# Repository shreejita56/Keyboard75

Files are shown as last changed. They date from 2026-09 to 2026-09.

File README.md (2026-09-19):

# Keyboard75


SO I made a custom 75 % layout Mechanical keyboard which has a rotor encoder at the top for brightness controlee as well . It is based on rp2040 chip  . SO I had to design the MCU circuit by myself as well . The PCB was designed on kicad and CAD was done on Fusion . firmware was written in VS-Code. It has a very compact design. The Keyboard also includes per switch LED and diodes to prevent ghosting. It connects to the PC via USB-C input .

## Features
 - Based on Rp2040 chip
 - had compact 75% keyboard layout
 - Per Switch LED and diode for ghosting prevention
 - USB-C Type for Connection
 - Uplifted CAD Design for comfortable typing

##  BOM

| Comment | Footprint | Quantity | Total Price ($) | Link |
|---|---|---:|---:|---|
| 33pF | 0603 | 4 | 0.0236 | https://jlcpcb.com/partdetail/2015-CL10C330JB8NNNC/C1663 |
| 0.1uF | 0603 | 10 | 0.124 | https://jlcpcb.com/partdetail/YAGEO-CC0603KRX7R9BB104/C14663 |
| 100nF | 0603 | 10 | 0.124 | https://jlcpcb.com/partdetail/YAGEO-CC0603KRX7R9BB104/C14663 |
| 10uF | 0603 | 4 | 0.1276 | https://jlcpcb.com/partdetail/20411-CL10A106KP8NNNC/C19702 |
| 1uF | 0603 | 4 | 0.0684 | https://jlcpcb.com/partdetail/16531-CL10A105KB8NNNC/C15849 |
| USB_C_Receptacle_USB2.0_16P | USB_C_Receptacle_G-Switch_GT-USB-7010ASV | 2 | 0.0988 | https://jlcpcb.com/partdetail/DEALON-USB_TYPE_C006/C2927026 |
| 5.1K | 0603 | 4 | 0.0076 | https://jlcpcb.com/partdetail/23913-0603WAF5101T5E/C23186 |
| 1K | 0603 | 4 | 0.0132 | https://jlcpcb.com/partdetail/21904-0603WAF1001T5E/C21190 |
| 27ohm | 0603 | 20 | 0.022 | https://jlcpcb.com/partdetail/23790019-RCA0327RJLF/C22356575 |
| 10K | 0603 | 4 | 0.0108 | https://jlcpcb.com/partdetail/26547-0603WAF1002T5E/C25804 |
| RP2040 | QFN-56-1EP_7x7mm_P0.4mm_EP3.2x3.2mm | 2 | 1.979 | https://jlcpcb.com/partdetail/RaspberryPi-RP2040/C2040 |
| 12MHz | Crystal_SMD_3225-4Pin_3.2x2.5mm | 5 | 2.14 | https://jlcpcb.com/partdetail/KDSDaishinku-DSX321G12MHz/C93234 |
| PCB + 3D Prints Cost | — | 1 | 30.80 | https://jlcpcb.com |
| PCBA Cost | — | 1 | 27.88 | https://jlcpcb.com |
| PCB Shipping | — | 1 | 14.03 | https://jlcpcb.com |
| Hot-swap | — | 90 | 6.75 | https://meckeys.com/shop/accessories/keyboard-accessories/key-switches/kailh-hot-swap-socket/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 |
| Mechanical Switch | — | 90 | 21.10 | https://meckeys.com/shop/accessories/keyboard-accessories/key-switches/akko-v3-pro-cream-black-switch/ |
| KEY-CAPS | — | 1 | 11.50 | https://meckeys.com/shop/accessories/keyboard-accessories/keycaps/side-engraved-keycap-set/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 |
| 0.1uF Capacitor | 0603 | 90 | 3.60 | https://sharvielectronics.com/product/0-1uf-16v-capacitor-0603-smd-package/ |
| 1N4007 Diodes | SOD-123FL | 90 | 2.60 | https://sharvielectronics.com/product/a7-1n4007-100v-1a-silicon-rectifier-diode-sod-123fl-smd-package/ |
| SK6812MINI-E | — | 90 | 8.10 | https://www.etstore.in/products/e9974?variant=48993209319675 |
| Components Shipping | — | 1 | 3.30 | https://www.etstore.in/ |
| **TOTAL** | — | — | **$132.67** | — |

### Schematic<br><br>


###  PCB Design<br><br>



### 3D Render <br><br>



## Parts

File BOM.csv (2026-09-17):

comment | footprint | description | quantity | total price | link
33pF | 0603 | 33pF 50V C0G ±5% 0603 Multilayer Ceramic Capacitors MLCC - SMD/SMT ROHS | 4 | 0.0236 | https://jlcpcb.com/partdetail/2015-CL10C330JB8NNNC/C1663
0.1uF | 0603 | 100nF 50V X7R ±10% 0603 Multilayer Ceramic Capacitors MLCC - SMD/SMT ROHS | 10 | 0.124 | https://jlcpcb.com/partdetail/YAGEO-CC0603KRX7R9BB104/C14663
100nf | 0603 | 100nF 50V X7R ±10% 0603 Multilayer Ceramic Capacitors MLCC - SMD/SMT ROHS | 10 | 0.124 | https://jlcpcb.com/partdetail/YAGEO-CC0603KRX7R9BB104/C14663
10uF | 0603 | 10V 10uF X5R ±10% 0603 Multilayer Ceramic Capacitors MLCC - SMD/SMT ROHS | 4 | 0.1276 | https://jlcpcb.com/partdetail/20411-CL10A106KP8NNNC/C19702
1uF | 0603 | 1uF 50V X5R ±10% 0603 Multilayer Ceramic Capacitors MLCC - SMD/SMT ROHS | 4 | 0.0684 | https://jlcpcb.com/partdetail/16531-CL10A105KB8NNNC/C15849
USB_C_Receptacle_USB2.0_16P | USB_C_Receptacle_G-Switch_GT-USB-7010ASV | -25℃~+85℃ 1 10000 times 5A 5V 6.8mm 6P Female Surface Mount, Right Angle Type-C SMD USB Connectors ROHS | 2 | 0.0988 | https://jlcpcb.com/partdetail/DEALON-USB_TYPE_C006/C2927026
5.1K | 0603 | -55℃~+155℃ 100mW 5.1kΩ 75V Thick Film Resistor ±1% ±100ppm/℃ 0603 Chip Resistor - Surface Mount ROHS | 4 | 0.0076 | https://jlcpcb.com/partdetail/23913-0603WAF5101T5E/C23186
1K | 0603 | -55℃~+155℃ 100mW 1kΩ 75V Thick Film Resistor ±1% ±100ppm/℃ 0603 Chip Resistor - Surface Mount ROHS | 4 | 0.0132 | https://jlcpcb.com/partdetail/21904-0603WAF1001T5E/C21190
27ohn | 0603 | -55℃~+155℃ 100mW 27Ω 75V Thick Film Resistor ±100ppm/℃ ±5% 0603 Chip Resistor - Surface Mount ROHS | 20 | 0.022 | https://jlcpcb.com/partdetail/23790019-RCA0327RJLF/C22356575
10K | 0603 | -55℃~+155℃ 100mW 10kΩ 75V Thick Film Resistor ±1% ±100ppm/℃ 0603 Chip Resistor - Surface Mount ROHS | 4 | 0.0108 | https://jlcpcb.com/partdetail/26547-0603WAF1002T5E/C25804
RP2040 | QFN-56-1EP_7x7mm_P0.4mm_EP3.2x3.2mm | 12bit 133MHz 30 LQFN-56(7x7) Microcontrollers (MCU/MPU/SOC) ROHS | 2 | 1.979 | https://jlcpcb.com/partdetail/RaspberryPi-RP2040/C2040
12MHz | Crystal_SMD_3225-4Pin_3.2x2.5mm | Crystal Oscillator SMD3225-4P Crystals ROHS | 5 | 2.14 | https://jlcpcb.com/partdetail/KDSDaishinku-DSX321G12MHz/C93234
PCB + 3D Prints Cost |  |  |  | 30.8 | https://jlcpcb.com
PCBA Cost |  |  |  | 27.88 | https://jlcpcb.com
PCB Shipping |  |  |  | 14.03 | https://jlcpcb.com
Hot-swap |  |  | 90 | 6.75 | https://meckeys.com/shop/accessories/keyboard-accessories/key-switches/kailh-hot-swap-socket/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
Mechanical Switch |  |  | 90 | 21.1 | https://meckeys.com/shop/accessories/keyboard-accessories/key-switches/akko-v3-pro-cream-black-switch/
KEY-CAPS |  |  | 1 | 11.5 | https://meckeys.com/shop/accessories/keyboard-accessories/keycaps/side-engraved-keycap-set/
0.1 uf Capacitor |  | Capacitors for Each LEDS | 90 | 3.6 | https://sharvielectronics.com/product/0-1uf-16v-capacitor-0603-smd-package/
1N4007 Diodes |  | for ghosting protection | 90 | 2.6 | https://sharvielectronics.com/product/a7-1n4007-100v-1a-silicon-rectifier-diode-sod-123fl-smd-package/
SK6812MINI-E |  | LEDS | 90 | 8.1 | https://www.etstore.in/products/e9974?variant=48993209319675
Components shipping (from all the three websites except jlcpcb) |  |  |  | 3.3 | www.etstore.in / https://sharvielectronics.com / https://meckeys.com
Total |  |  |  | $132.67

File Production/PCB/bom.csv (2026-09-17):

Designator | Footprint | Quantity | Value | LCSC Part #
_6, _5, _4, _3, _2, |  | 6
C1, C10, C11, C12, C13, C14, C15, C16, C17, C18, C19, C2, C20, C21, C22, C23, C24, C25, C26, C27, C28, C29, C3, C30, C31, C32, C33, C34, C35, C36, C37, C38, C39, C4, C40, C41, C42, C43, C44, C45, C46, C47, C48, C49, C5, C50, C51, C52, C53, C54, C55, C56, C57, C58, C59, C6, C60, C61, C62, C63, C64, C65, C66, C67, C68, C69, C7, C70, C71, C72, C73, C74, C75, C76, C77, C78, C79, C8, C80, C81, C82, C9 | 0805 | 82 | 0.1 uf
C83, C84 | 0603 | 2 | 33pF
C86, C88, C92 | 0603 | 3 | 0.1uF
C87, C91 | 0603 | 2 | 10uF
C94, C98 | 0603 | 2 | 1uF
C95, C97 | 0603 | 2 | 100 nf
D1, D10, D11, D12, D13, D14, D15, D16, D17, D18, D19, D2, D20, D21, D22, D23, D24, D25, D26, D27, D28, D29, D3, D30, D31, D32, D33, D34, D35, D36, D37, D38, D39, D4, D40, D41, D42, D43, D44, D45, D46, D47, D48, D49, D5, D50, D51, D52, D53, D54, D55, D56, D57, D58, D59, D6, D60, D61, D62, D63, D64, D65, D66, D67, D68, D69, D7, D70, D71, D72, D73, D74, D75, D76, D77, D78, D79, D8, D80, D81, D82, D83, D9 | 0805 | 83 | D
J1 | USB_C_Receptacle_G-Switch_GT-USB-7010ASV | 1 | USB_C_Receptacle_USB2.0_16P
LED1 | MX_SK6812MINI-E | 1 | C
LED10, LED11, LED12, LED13, LED14, LED15, LED16, LED17, LED18, LED19, LED2, LED20, LED21, LED22, LED23, LED24, LED25, LED26, LED27, LED28, LED29, LED3, LED30, LED31, LED32, LED33, LED34, LED35, LED36, LED37, LED38, LED39, LED4, LED40, LED41, LED42, LED43, LED44, LED45, LED46, LED47, LED48, LED49, LED5, LED50, LED51, LED52, LED53, LED54, LED55, LED56, LED57, LED58, LED59, LED6, LED60, LED61, LED62, LED63, LED64, LED65, LED66, LED67, LED68, LED69, LED7, LED70, LED71, LED72, LED73, LED74, LED75, LED76, LED77, LED78, LED79, LED8, LED80, LED81, LED82, LED9 | MX_SK6812MINI-E | 81 | ~
R14, R7 | 0603 | 2 | 10K
R3, R4 | 0603 | 2 | 5.1K
R5, R6 | 0603 | 2 | 1K
R8, R9 | 0603 | 2 | 27 ohn
ST28, ST57, ST59 | Stabilizer_Cherry_MX_2.00u | 3 | MountingHole
ST76 | Stabilizer_Cherry_MX_6.25u | 1 | MountingHole
SW1 | SW_Hotswap_Kailh_MX_1.00u | 1 | ESC
SW10 | SW_Hotswap_Kailh_MX_1.00u | 1 | F9
SW11 | SW_Hotswap_Kailh_MX_1.00u | 1 | F10
SW12 | SW_Hotswap_Kailh_MX_1.00u | 1 | F11
SW13 | SW_Hotswap_Kailh_MX_1.00u | 1 | F12
SW14 | SW_Hotswap_Kailh_MX_1.00u | 1 | Delete
SW15 | SW_Hotswap_Kailh_MX_1.00u | 1 | `
SW16 | SW_Hotswap_Kailh_MX_1.00u | 1 | 1
SW17 | SW_Hotswap_Kailh_MX_1.00u | 1 | 2
SW18 | SW_Hotswap_Kailh_MX_1.00u | 1 | 3
SW19 | SW_Hotswap_Kailh_MX_1.00u | 1 | 4
SW2 | SW_Hotswap_Kailh_MX_1.00u | 1 | F1
SW20 | SW_Hotswap_Kailh_MX_1.00u | 1 | 5
SW21 | SW_Hotswap_Kailh_MX_1.00u | 1 | 6
SW22 | SW_Hotswap_Kailh_MX_1.00u | 1 | 7
SW23 | SW_Hotswap_Kailh_MX_1.00u | 1 | 8
SW24 | SW_Hotswap_Kailh_MX_1.00u | 1 | 9
SW25 | SW_Hotswap_Kailh_MX_1.00u | 1 | 0
SW26 | SW_Hotswap_Kailh_MX_1.00u | 1 | -
SW27 | SW_Hotswap_Kailh_MX_1.00u | 1 | +
SW28 | SW_Hotswap_Kailh_MX_1.00u | 1 | Backspace
SW29 | SW_Hotswap_Kailh_MX_1.00u | 1 | Home
SW3 | SW_Hotswap_Kailh_MX_1.00u | 1 | F2
SW30 | SW_Hotswap_Kailh_MX_1.00u | 1 | Tab
SW31 | SW_Hotswap_Kailh_MX_1.00u | 1 | Q
SW32 | SW_Hotswap_Kailh_MX_1.00u | 1 | W
SW33 | SW_Hotswap_Kailh_MX_1.00u | 1 | E
SW34 | SW_Hotswap_Kailh_MX_1.00u | 1 | R
SW35 | SW_Hotswap_Kailh_MX_1.00u | 1 | T
SW36 | SW_Hotswap_Kailh_MX_1.00u | 1 | Y
SW37 | SW_Hotswap_Kailh_MX_1.00u | 1 | U
SW38 | SW_Hotswap_Kailh_MX_1.00u | 1 | I
SW39 | SW_Hotswap_Kailh_MX_1.00u | 1 | O
SW4 | SW_Hotswap_Kailh_MX_1.00u | 1 | F3
SW40 | SW_Hotswap_Kailh_MX_1.00u | 1 | P
SW41 | SW_Hotswap_Kailh_MX_1.00u | 1 | [
SW42 | SW_Hotswap_Kailh_MX_1.00u | 1 | ]
SW43 | SW_Hotswap_Kailh_MX_1.00u | 1 | \
SW44 | SW_Hotswap_Kailh_MX_1.00u | 1 | Pg Up
SW45 | SW_Hotswap_Kailh_MX_1.00u | 1 | Caps Lock
SW46 | SW_Hotswap_Kailh_MX_1.00u | 1 | A
SW47 | SW_Hotswap_Kailh_MX_1.00u | 1 | S
SW48 | SW_Hotswap_Kailh_MX_1.00u | 1 | D
SW49 | SW_Hotswap_Kailh_MX_1.00u | 1 | F
SW5 | SW_Hotswap_Kailh_MX_1.00u | 1 | F4
SW50 | SW_Hotswap_Kailh_MX_1.00u | 1 | G
SW51 | SW_Hotswap_Kailh_MX_1.00u | 1 | H
SW52 | SW_Hotswap_Kailh_MX_1.00u | 1 | J
SW53 | SW_Hotswap_Kailh_MX_1.00u | 1 | K
SW54 | SW_Hotswap_Kailh_MX_1.00u | 1 | L
SW55 | SW_Hotswap_Kailh_MX_1.00u | 1 | ;
SW56 | SW_Hotswap_Kailh_MX_1.00u | 1 | "
SW57 | SW_Hotswap_Kailh_MX_1.00u | 1 | Enter
SW58 | SW_Hotswap_Kailh_MX_1.00u | 1 | Pg Dn
SW59 | SW_Hotswap_Kailh_MX_1.00u | 1 | L Shift
SW6 | SW_Hotswap_Kailh_MX_1.00u | 1 | F5
SW60 | SW_Hotswap_Kailh_MX_1.00u | 1 | Z
SW61 | SW_Hotswap_Kailh_MX_1.00u | 1 | X
SW62 | SW_Hotswap_Kailh_MX_1.00u | 1 | C
SW63 | SW_Hotswap_Kailh_MX_1.00u | 1 | V
SW64 | SW_Hotswap_Kailh_MX_1.00u | 1 | B
SW65 | SW_Hotswap_Kailh_MX_1.00u | 1 | N
SW66 | SW_Hotswap_Kailh_MX_1.00u | 1 | M
SW67 | SW_Hotswap_Kailh_MX_1.00u | 1 | ,
SW68 | SW_Hotswap_Kailh_MX_1.00u | 1 | .
SW69 | SW_Hotswap_Kailh_MX_1.00u | 1 | /
SW7 | SW_Hotswap_Kailh_MX_1.00u | 1 | F6
SW70 | SW_Hotswap_Kailh_MX_1.00u | 1 | R Shift
SW71 | SW_Hotswap_Kailh_MX_1.00u | 1 | Up Arrow
SW72 | SW_Hotswap_Kailh_MX_1.00u | 1 | End
SW73 | SW_Hotswap_Kailh_MX_1.00u | 1 | L Ctrl
SW74 | SW_Hotswap_Kailh_MX_1.00u | 1 | Win
SW75, SW77 | SW_Hotswap_Kailh_MX_1.00u | 2 | Alt
SW76 | SW_Hotswap_Kailh_MX_1.00u | 1 | Space
SW78 | SW_Hotswap_Kailh_MX_1.00u | 1 | Fn
SW79 | SW_Hotswap_Kailh_MX_1.00u | 1 | R Ctrl
SW8 | SW_Hotswap_Kailh_MX_1.00u | 1 | F7
SW80 | SW_Hotswap_Kailh_MX_1.00u | 1 | Left Arrow
SW81 | SW_Hotswap_Kailh_MX_1.00u | 1 | Down Arrow
SW82 | SW_Hotswap_Kailh_MX_1.00u | 1 | Right Arrow
SW83 | RotaryEncoder_Alps_EC11E-Switch_Vertical_H20mm | 1 | RotaryEncoder_Switch_MP
SW84, SW85 | SW_Push_SPST_NO_Alps_SKRK | 2 | SW_Push
SW9 | SW_Hotswap_Kailh_MX_1.00u | 1 | F8
U1 | QFN-56-1EP_7x7mm_P0.4mm_EP3.2x3.2mm | 1 | RP2040
U2 | SOT-23 | 1 | MCP1700x-330xxTT
U4 | Winbond_USON-8-1EP_3x2mm_P0.5mm_EP0.2x1.6mm | 1 | W25Q16JVUXIQ TR
Y1 | Crystal_SMD_3225-4Pin_3.2x2.5mm | 1 | 12 MHz

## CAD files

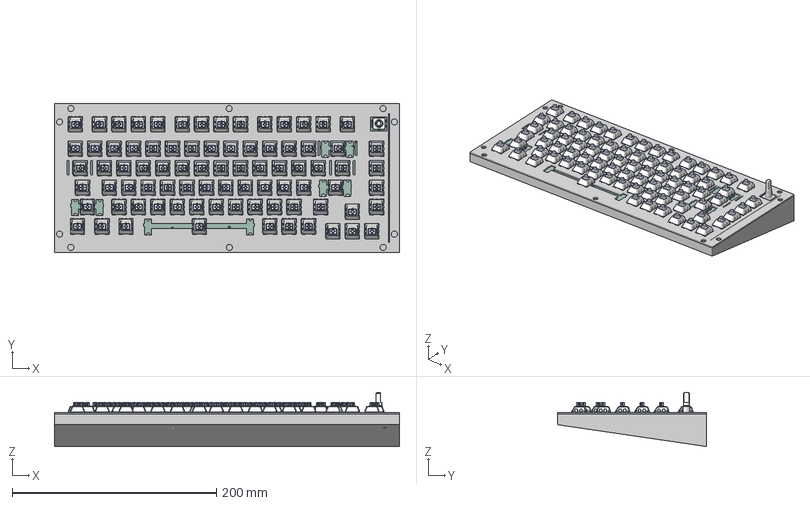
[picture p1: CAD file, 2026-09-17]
CAD/75Keyboard[SET].step
338.0 x 146.0 x 53.0 mm

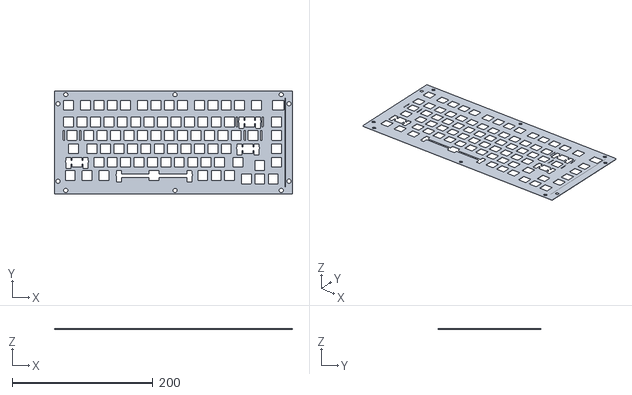
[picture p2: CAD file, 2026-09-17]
Production/CAD/TOP(F).stl
338.0 x 146.0 x 1.50

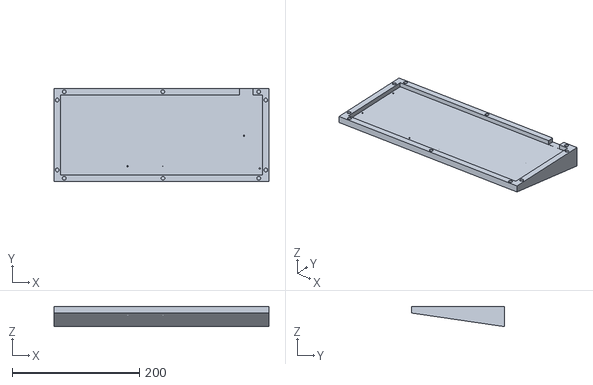
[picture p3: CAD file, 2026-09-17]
Production/CAD/BASE(F).stl
338.0 x 146.0 x 31.9

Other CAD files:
CAD/75Keyboard.f3z

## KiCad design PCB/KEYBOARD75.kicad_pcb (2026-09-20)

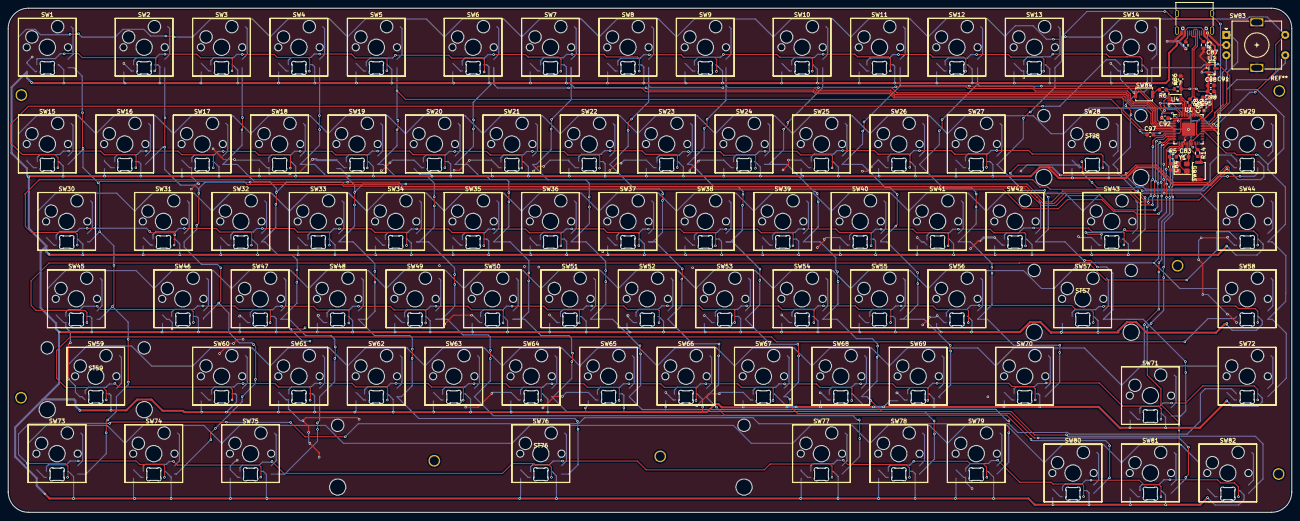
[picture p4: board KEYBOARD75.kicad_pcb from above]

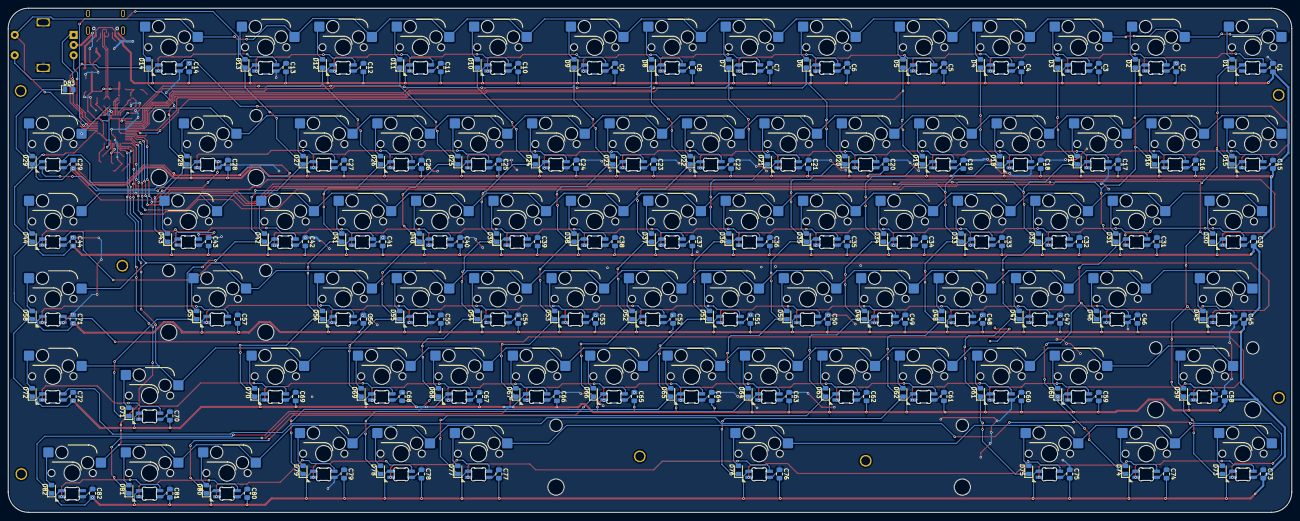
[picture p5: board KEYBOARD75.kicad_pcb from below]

Board: 2 copper layers, 315.9 x 124.1 mm, 360 parts (165 on the bottom side), 208 nets.

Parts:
C1, C2, C3, C4, C5, C6, C7, C8, C9, C10, C11, C12, C13, C14, C15, C16, C17, C18, C19, C20, C21, C22, C23, C24, C25, C26, C27, C28, C29, C30, C31, C32, C33, C34, C35, C36, C37, C38, C39, C40, C41, C42, C43, C44, C45, C46, C47, C48, C49, C50, C51, C52, C53, C54, C55, C56, C57, C58, C59, C60, C61, C62, C63, C64, C65, C66, C67, C68, C69, C70, C71, C72, C73, C74, C75, C76, C77, C78, C79, C80, C81, C82: 0.1 uf; C_0805_2012Metric_Pad1.18x1.45mm_HandSolder
C83, C84: 33pF; C_0603_1608Metric
C86, C88, C92: 0.1uF; C_0603_1608Metric
C87, C91: 10uF; C_0603_1608Metric
C94: 1uF; C_0603_1608Metric
C95, C97: 100 nf; C_0603_1608Metric
C98: 1uf; C_0603_1608Metric
D1, D2, D3, D4, D5, D6, D7, D8, D9, D10, D11, D12, D13, D14, D15, D16, D17, D18, D19, D20, D21, D22, D23, D24, D25, D26, D27, D28, D29, D30, D31, D32, D33, D34, D35, D36, D37, D38, D39, D40, D41, D42, D43, D44, D45, D46, D47, D48, D49, D50, D51, D52, D53, D54, D55, D56, D57, D58, D59, D60, D61, D62, D63, D64, D65, D66, D67, D68, D69, D70, D71, D72, D73, D74, D75, D76, D77, D78, D79, D80, D81, D82, D83: D; D_0805_2012Metric_Pad1.15x1.40mm_HandSolder
J1: USB_C_Receptacle_USB2.0_16P; USB_C_Receptacle_G-Switch_GT-USB-7010ASV
LED1: C; MX_SK6812MINI-E
LED2, LED3, LED4, LED5, LED6, LED7, LED8, LED9, LED10, LED11, LED12, LED13, LED14, LED15, LED16, LED17, LED18, LED19, LED20, LED21, LED22, LED23, LED24, LED25, LED26, LED27, LED28, LED29, LED30, LED31, LED32, LED33, LED34, LED35, LED36, LED37, LED38, LED39, LED40, LED41, LED42, LED43, LED44, LED45, LED46, LED47, LED48, LED49, LED50, LED51, LED52, LED53, LED54, LED55, LED56, LED57, LED58, LED59, LED60, LED61, LED62, LED63, LED64, LED65, LED66, LED67, LED68, LED69, LED70, LED71, LED72, LED73, LED74, LED75, LED76, LED77, LED78, LED79, LED80, LED81, LED82: MX_SK6812MINI-E
R3, R4: 5.1K; R_0603_1608Metric
R5, R6: 1K; R_0603_1608Metric
R7, R14: 10K; R_0603_1608Metric
R8, R9: 27 ohn; R_0603_1608Metric
ST28, ST57, ST59: MountingHole; Stabilizer_Cherry_MX_2.00u
ST76: MountingHole; Stabilizer_Cherry_MX_6.25u
SW1: ESC; SW_Hotswap_Kailh_MX_1.00u
SW2: F1; SW_Hotswap_Kailh_MX_1.00u
SW3: F2; SW_Hotswap_Kailh_MX_1.00u
SW4: F3; SW_Hotswap_Kailh_MX_1.00u
SW5: F4; SW_Hotswap_Kailh_MX_1.00u
SW6: F5; SW_Hotswap_Kailh_MX_1.00u
SW7: F6; SW_Hotswap_Kailh_MX_1.00u
SW8: F7; SW_Hotswap_Kailh_MX_1.00u
SW9: F8; SW_Hotswap_Kailh_MX_1.00u
SW10: F9; SW_Hotswap_Kailh_MX_1.00u
SW11: F10; SW_Hotswap_Kailh_MX_1.00u
SW12: F11; SW_Hotswap_Kailh_MX_1.00u
SW13: F12; SW_Hotswap_Kailh_MX_1.00u
SW14: Delete; SW_Hotswap_Kailh_MX_1.00u
SW15: `; SW_Hotswap_Kailh_MX_1.00u
SW16: 1; SW_Hotswap_Kailh_MX_1.00u
SW17: 2; SW_Hotswap_Kailh_MX_1.00u
SW18: 3; SW_Hotswap_Kailh_MX_1.00u
SW19: 4; SW_Hotswap_Kailh_MX_1.00u
SW20: 5; SW_Hotswap_Kailh_MX_1.00u
SW21: 6; SW_Hotswap_Kailh_MX_1.00u
SW22: 7; SW_Hotswap_Kailh_MX_1.00u
SW23: 8; SW_Hotswap_Kailh_MX_1.00u
SW24: 9; SW_Hotswap_Kailh_MX_1.00u
SW25: 0; SW_Hotswap_Kailh_MX_1.00u
SW26: -; SW_Hotswap_Kailh_MX_1.00u
SW27: +; SW_Hotswap_Kailh_MX_1.00u
SW28: Backspace; SW_Hotswap_Kailh_MX_1.00u
SW29: Home; SW_Hotswap_Kailh_MX_1.00u
SW30: Tab; SW_Hotswap_Kailh_MX_1.00u
SW31: Q; SW_Hotswap_Kailh_MX_1.00u
SW32: W; SW_Hotswap_Kailh_MX_1.00u
SW33: E; SW_Hotswap_Kailh_MX_1.00u
SW34: R; SW_Hotswap_Kailh_MX_1.00u
SW35: T; SW_Hotswap_Kailh_MX_1.00u
SW36: Y; SW_Hotswap_Kailh_MX_1.00u
SW37: U; SW_Hotswap_Kailh_MX_1.00u
SW38: I; SW_Hotswap_Kailh_MX_1.00u
SW39: O; SW_Hotswap_Kailh_MX_1.00u
SW40: P; SW_Hotswap_Kailh_MX_1.00u
SW41: [; SW_Hotswap_Kailh_MX_1.00u
SW42: ]; SW_Hotswap_Kailh_MX_1.00u
SW43: \; SW_Hotswap_Kailh_MX_1.00u
SW44: Pg Up; SW_Hotswap_Kailh_MX_1.00u
SW45: Caps Lock; SW_Hotswap_Kailh_MX_1.00u
SW46: A; SW_Hotswap_Kailh_MX_1.00u
SW47: S; SW_Hotswap_Kailh_MX_1.00u
SW48: D; SW_Hotswap_Kailh_MX_1.00u
SW49: F; SW_Hotswap_Kailh_MX_1.00u
SW50: G; SW_Hotswap_Kailh_MX_1.00u
SW51: H; SW_Hotswap_Kailh_MX_1.00u
SW52: J; SW_Hotswap_Kailh_MX_1.00u
SW53: K; SW_Hotswap_Kailh_MX_1.00u
SW54: L; SW_Hotswap_Kailh_MX_1.00u
SW55: ;; SW_Hotswap_Kailh_MX_1.00u
SW56: "; SW_Hotswap_Kailh_MX_1.00u
SW57: Enter; SW_Hotswap_Kailh_MX_1.00u
SW58: Pg Dn; SW_Hotswap_Kailh_MX_1.00u
SW59: L Shift; SW_Hotswap_Kailh_MX_1.00u
SW60: Z; SW_Hotswap_Kailh_MX_1.00u
SW61: X; SW_Hotswap_Kailh_MX_1.00u
SW62: C; SW_Hotswap_Kailh_MX_1.00u
SW63: V; SW_Hotswap_Kailh_MX_1.00u
SW64: B; SW_Hotswap_Kailh_MX_1.00u
SW65: N; SW_Hotswap_Kailh_MX_1.00u
SW66: M; SW_Hotswap_Kailh_MX_1.00u
SW67: ,; SW_Hotswap_Kailh_MX_1.00u
SW68: .; SW_Hotswap_Kailh_MX_1.00u
SW69: /; SW_Hotswap_Kailh_MX_1.00u
SW70: R Shift; SW_Hotswap_Kailh_MX_1.00u
SW71: Up Arrow; SW_Hotswap_Kailh_MX_1.00u
SW72: End; SW_Hotswap_Kailh_MX_1.00u
SW73: L Ctrl; SW_Hotswap_Kailh_MX_1.00u
SW74: Win; SW_Hotswap_Kailh_MX_1.00u
SW75, SW77: Alt; SW_Hotswap_Kailh_MX_1.00u
SW76: Space; SW_Hotswap_Kailh_MX_1.00u
SW78: Fn; SW_Hotswap_Kailh_MX_1.00u
SW79: R Ctrl; SW_Hotswap_Kailh_MX_1.00u
SW80: Left Arrow; SW_Hotswap_Kailh_MX_1.00u
SW81: Down Arrow; SW_Hotswap_Kailh_MX_1.00u
SW82: Right Arrow; SW_Hotswap_Kailh_MX_1.00u
SW83: RotaryEncoder_Switch_MP; RotaryEncoder_Alps_EC11E-Switch_Vertical_H20mm
SW84, SW85: SW_Push; SW_Push_SPST_NO_Alps_SKRK
U1: RP2040; QFN-56-1EP_7x7mm_P0.4mm_EP3.2x3.2mm
U2: MCP1700x-330xxTT; SOT-23
U4: W25Q16JVUXIQ TR; Winbond_USON-8-1EP_3x2mm_P0.5mm_EP0.2x1.6mm
Y1: 12 MHz; Crystal_SMD_3225-4Pin_3.2x2.5mm

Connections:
+3.3V: C86.1, C88.1, C91.1, C92.1, C97.2, C98.2, R7.2, R14.2, U1.1 (IOVDD), U1.10 (IOVDD), U1.22 (IOVDD), U1.33 (IOVDD), U1.42 (IOVDD), U1.43 (ADC_AVDD), U1.44 (VREG_IN), U1.48 (USB_VDD), U1.49 (IOVDD), U2.2 (VO), U4.8 (VCC)
+5V: C1.2, C2.2, C3.2, C4.2, C5.2, C6.2, C7.2, C8.2, C9.2, C10.2, C11.2, C12.2, C13.2, C14.2, C15.2, C16.2, C17.2, C18.2, C19.2, C20.2, C21.2, C22.2, C23.2, C24.2, C25.2, C26.2, C27.2, C28.2, C29.2, C30.2, C31.2, C32.2, C33.2, C34.2, C35.2, C36.2, C37.2, C38.2, C39.2, C40.2, C41.2, C42.2, C43.2, C44.2, C45.2, C46.2, C47.2, C48.2, C49.2, C50.2, C51.2, C52.2, C53.2, C54.2, C55.2, C56.2, C57.2, C58.2, C59.2, C60.2, C61.2, C62.2, C63.2, C64.2, C65.2, C66.2, C67.2, C68.2, C69.2, C70.2, C71.2, C72.2, C73.2, C74.2, C75.2, C76.2, C77.2, C78.2, C79.2, C80.2, C81.2, C82.2, C87.1, J1.A4 (VBUS), J1.A9 (VBUS), J1.B4 (VBUS), J1.B9 (VBUS), LED1.4 (VDD), LED2.4 (VDD), LED3.4 (VDD), LED4.4 (VDD), LED5.4 (VDD), LED6.4 (VDD), LED7.4 (VDD), LED8.4 (VDD), LED9.4 (VDD), LED10.4 (VDD), LED11.4 (VDD), LED12.4 (VDD), LED13.4 (VDD), LED14.4 (VDD), LED15.4 (VDD), LED16.4 (VDD), LED17.4 (VDD), LED18.4 (VDD), LED19.4 (VDD), LED20.4 (VDD), LED21.4 (VDD), LED22.4 (VDD), LED23.4 (VDD), LED24.4 (VDD), LED25.4 (VDD), LED26.4 (VDD), LED27.4 (VDD), LED28.4 (VDD), LED29.4 (VDD), LED30.4 (VDD), LED31.4 (VDD), LED32.4 (VDD), LED33.4 (VDD), LED34.4 (VDD), LED35.4 (VDD), LED36.4 (VDD), LED37.4 (VDD), LED38.4 (VDD), LED39.4 (VDD), LED40.4 (VDD), LED41.4 (VDD), LED42.4 (VDD), LED43.4 (VDD), LED44.4 (VDD), LED45.4 (VDD), LED46.4 (VDD), LED47.4 (VDD), LED48.4 (VDD), LED49.4 (VDD), LED50.4 (VDD), LED51.4 (VDD), LED52.4 (VDD), LED53.4 (VDD), LED54.4 (VDD), LED55.4 (VDD), LED56.4 (VDD), LED57.4 (VDD), LED58.4 (VDD), LED59.4 (VDD), LED60.4 (VDD), LED61.4 (VDD), LED62.4 (VDD), LED63.4 (VDD), LED64.4 (VDD), LED65.4 (VDD), LED66.4 (VDD), LED67.4 (VDD), LED68.4 (VDD), LED69.4 (VDD), LED70.4 (VDD), LED71.4 (VDD), LED72.4 (VDD), LED73.4 (VDD), LED74.4 (VDD), LED75.4 (VDD), LED76.4 (VDD), LED77.4 (VDD), LED78.4 (VDD), LED79.4 (VDD), LED80.4 (VDD), LED81.4 (VDD), LED82.4 (VDD), U2.3 (VI)
C1: D1.1 (K), D15.1 (K), D30.1 (K), D45.1 (K), D59.1 (K), D73.1 (K), U1.14 (GPIO11)
C2: D2.1 (K), D16.1 (K), D31.1 (K), D46.1 (K), D60.1 (K), D74.1 (K), U1.13 (GPIO10)
C3: D3.1 (K), D17.1 (K), D32.1 (K), D47.1 (K), D61.1 (K), D75.1 (K), U1.12 (GPIO9)
C4: D4.1 (K), D18.1 (K), D33.1 (K), D48.1 (K), D62.1 (K), D76.1 (K), U1.11 (GPIO8)
C5: D5.1 (K), D19.1 (K), D34.1 (K), D49.1 (K), D63.1 (K), D77.1 (K), U1.9 (GPIO7)
C6: D6.1 (K), D20.1 (K), D35.1 (K), D50.1 (K), D64.1 (K), D78.1 (K), U1.8 (GPIO6)
C7: D7.1 (K), D21.1 (K), D36.1 (K), D51.1 (K), D65.1 (K), D79.1 (K), U1.7 (GPIO5)
C8: D8.1 (K), D22.1 (K), D37.1 (K), D52.1 (K), D66.1 (K), D80.1 (K), U1.6 (GPIO4)
C9: D9.1 (K), D23.1 (K), D38.1 (K), D53.1 (K), D67.1 (K), D81.1 (K), U1.5 (GPIO3)
C10: D10.1 (K), D24.1 (K), D39.1 (K), D54.1 (K), D68.1 (K), D82.1 (K), U1.4 (GPIO2)
C11: D11.1 (K), D25.1 (K), D40.1 (K), D55.1 (K), D69.1 (K), U1.3 (GPIO1)
C12: D12.1 (K), D26.1 (K), D41.1 (K), D56.1 (K), D70.1 (K), U1.2 (GPIO0)
C13: D13.1 (K), D27.1 (K), D42.1 (K), D57.1 (K), D71.1 (K), U1.38 (GPIO26_ADC0)
C14: D14.1 (K), D28.1 (K), D43.1 (K), U1.36 (GPIO24)
C15: D29.1 (K), D44.1 (K), D58.1 (K), D72.1 (K), D83.1 (K), U1.34 (GPIO22)
E-A: SW83.A, U1.39 (GPIO27_ADC1)
E-B: SW83.B, U1.40 (GPIO28_ADC2)
E-SW1: D83.2 (A), SW83.S1
E-SW2: SW1.1, SW2.1, SW3.1, SW4.1, SW5.1, SW6.1, SW7.1, SW8.1, SW9.1, SW10.1, SW11.1, SW12.1, SW13.1, SW14.1, SW83.S2, U1.37 (GPIO25)
GND: C1.1, C2.1, C3.1, C4.1, C5.1, C6.1, C7.1, C8.1, C9.1, C10.1, C11.1, C12.1, C13.1, C14.1, C15.1, C16.1, C17.1, C18.1, C19.1, C20.1, C21.1, C22.1, C23.1, C24.1, C25.1, C26.1, C27.1, C28.1, C29.1, C30.1, C31.1, C32.1, C33.1, C34.1, C35.1, C36.1, C37.1, C38.1, C39.1, C40.1, C41.1, C42.1, C43.1, C44.1, C45.1, C46.1, C47.1, C48.1, C49.1, C50.1, C51.1, C52.1, C53.1, C54.1, C55.1, C56.1, C57.1, C58.1, C59.1, C60.1, C61.1, C62.1, C63.1, C64.1, C65.1, C66.1, C67.1, C68.1, C69.1, C70.1, C71.1, C72.1, C73.1, C74.1, C75.1, C76.1, C77.1, C78.1, C79.1, C80.1, C81.1, C82.1, C83.1, C84.1, C86.2, C87.2, C88.2, C91.2, C92.2, C94.1, C95.1, C97.1, C98.1, J1.A1 (GND), J1.A12 (GND), J1.B1 (GND), J1.B12 (GND), LED1.2 (VSS), LED2.2 (VSS), LED3.2 (VSS), LED4.2 (VSS), LED5.2 (VSS), LED6.2 (VSS), LED7.2 (VSS), LED8.2 (VSS), LED9.2 (VSS), LED10.2 (VSS), LED11.2 (VSS), LED12.2 (VSS), LED13.2 (VSS), LED14.2 (VSS), LED15.2 (VSS), LED16.2 (VSS), LED17.2 (VSS), LED18.2 (VSS), LED19.2 (VSS), LED20.2 (VSS), LED21.2 (VSS), LED22.2 (VSS), LED23.2 (VSS), LED24.2 (VSS), LED25.2 (VSS), LED26.2 (VSS), LED27.2 (VSS), LED28.2 (VSS), LED29.2 (VSS), LED30.2 (VSS), LED31.2 (VSS), LED32.2 (VSS), LED33.2 (VSS), LED34.2 (VSS), LED35.2 (VSS), LED36.2 (VSS), LED37.2 (VSS), LED38.2 (VSS), LED39.2 (VSS), LED40.2 (VSS), LED41.2 (VSS), LED42.2 (VSS), LED43.2 (VSS), LED44.2 (VSS), LED45.2 (VSS), LED46.2 (VSS), LED47.2 (VSS), LED48.2 (VSS), LED49.2 (VSS), LED50.2 (VSS), LED51.2 (VSS), LED52.2 (VSS), LED53.2 (VSS), LED54.2 (VSS), LED55.2 (VSS), LED56.2 (VSS), LED57.2 (VSS), LED58.2 (VSS), LED59.2 (VSS), LED60.2 (VSS), LED61.2 (VSS), LED62.2 (VSS), LED63.2 (VSS), LED64.2 (VSS), LED65.2 (VSS), LED66.2 (VSS), LED67.2 (VSS), LED68.2 (VSS), LED69.2 (VSS), LED70.2 (VSS), LED71.2 (VSS), LED72.2 (VSS), LED73.2 (VSS), LED74.2 (VSS), LED75.2 (VSS), LED76.2 (VSS), LED77.2 (VSS), LED78.2 (VSS), LED79.2 (VSS), LED80.2 (VSS), LED81.2 (VSS), LED82.2 (VSS), R3.2, R4.2, SW83.C, SW83.MP, SW84.1, SW85.1, U1.19 (TESTEN), U1.57 (GND), U2.1 (GND), U4.4 (GND), Y1.2, Y1.4
unnamed: C84.2, R5.1, Y1.1
unnamed: D1.2 (A), SW1.2
unnamed: D2.2 (A), SW2.2
unnamed: D3.2 (A), SW3.2
unnamed: D4.2 (A), SW4.2
unnamed: D5.2 (A), SW5.2
unnamed: D6.2 (A), SW6.2
unnamed: D7.2 (A), SW7.2
unnamed: D8.2 (A), SW8.2
unnamed: D9.2 (A), SW9.2
unnamed: D10.2 (A), SW10.2
unnamed: D11.2 (A), SW11.2
unnamed: D12.2 (A), SW12.2
unnamed: D13.2 (A), SW13.2
unnamed: D14.2 (A), SW14.2
unnamed: D15.2 (A), SW15.2
unnamed: D16.2 (A), SW16.2
unnamed: D17.2 (A), SW17.2
unnamed: D18.2 (A), SW18.2
unnamed: D19.2 (A), SW19.2
unnamed: D20.2 (A), SW20.2
unnamed: D21.2 (A), SW21.2
unnamed: D22.2 (A), SW22.2
unnamed: D23.2 (A), SW23.2
unnamed: D24.2 (A), SW24.2
unnamed: D25.2 (A), SW25.2
unnamed: D26.2 (A), SW26.2
unnamed: D27.2 (A), SW27.2
unnamed: D28.2 (A), SW28.2
unnamed: D29.2 (A), SW29.2
unnamed: D30.2 (A), SW30.2
unnamed: D31.2 (A), SW31.2
unnamed: D32.2 (A), SW32.2
unnamed: D33.2 (A), SW33.2
unnamed: D34.2 (A), SW34.2
unnamed: D35.2 (A), SW35.2
unnamed: D36.2 (A), SW36.2
unnamed: D37.2 (A), SW37.2
unnamed: D38.2 (A), SW38.2
unnamed: D39.2 (A), SW39.2
unnamed: D40.2 (A), SW40.2
unnamed: D41.2 (A), SW41.2
unnamed: D42.2 (A), SW42.2
unnamed: D43.2 (A), SW43.2
unnamed: D44.2 (A), SW44.2
unnamed: D45.2 (A), SW45.2
unnamed: D46.2 (A), SW46.2
unnamed: D47.2 (A), SW47.2
unnamed: D48.2 (A), SW48.2
unnamed: D49.2 (A), SW49.2
unnamed: D50.2 (A), SW50.2
unnamed: D51.2 (A), SW51.2
unnamed: D52.2 (A), SW52.2
unnamed: D53.2 (A), SW53.2
unnamed: D54.2 (A), SW54.2
unnamed: D55.2 (A), SW55.2
unnamed: D56.2 (A), SW56.2
unnamed: D57.2 (A), SW57.2
unnamed: D58.2 (A), SW58.2
unnamed: D59.2 (A), SW59.2
unnamed: D60.2 (A), SW60.2
unnamed: D61.2 (A), SW61.2
unnamed: D62.2 (A), SW62.2
unnamed: D63.2 (A), SW63.2
unnamed: D64.2 (A), SW64.2
unnamed: D65.2 (A), SW65.2
unnamed: D66.2 (A), SW66.2
unnamed: D67.2 (A), SW67.2
unnamed: D68.2 (A), SW68.2
unnamed: D69.2 (A), SW69.2
unnamed: D70.2 (A), SW70.2
unnamed: D71.2 (A), SW71.2
unnamed: D72.2 (A), SW72.2
unnamed: D73.2 (A), SW73.2
unnamed: D74.2 (A), SW74.2
unnamed: D75.2 (A), SW75.2
unnamed: D76.2 (A), SW76.2
unnamed: D77.2 (A), SW77.2
unnamed: D78.2 (A), SW78.2
unnamed: D79.2 (A), SW79.2
unnamed: D80.2 (A), SW80.2
unnamed: D81.2 (A), SW81.2
unnamed: D82.2 (A), SW82.2
unnamed: J1.A5 (CC1), R3.1
unnamed: J1.B5 (CC2), R4.1
unnamed: LED1.1 (DOUT), LED2.3 (DIN)
unnamed: LED2.1 (DOUT), LED3.3 (DIN)
unnamed: LED3.1 (DOUT), LED4.3 (DIN)
unnamed: LED4.1 (DOUT), LED5.3 (DIN)
unnamed: LED5.1 (DOUT), LED6.3 (DIN)
unnamed: LED6.1 (DOUT), LED7.3 (DIN)
unnamed: LED7.1 (DOUT), LED8.3 (DIN)
unnamed: LED8.1 (DOUT), LED9.3 (DIN)
unnamed: LED9.1 (DOUT), LED10.3 (DIN)
unnamed: LED10.1 (DOUT), LED11.3 (DIN)
unnamed: LED11.1 (DOUT), LED12.3 (DIN)
unnamed: LED12.1 (DOUT), LED13.3 (DIN)
unnamed: LED13.1 (DOUT), LED14.3 (DIN)
unnamed: LED14.1 (DOUT), LED15.3 (DIN)
unnamed: LED15.1 (DOUT), LED16.3 (DIN)
unnamed: LED16.1 (DOUT), LED17.3 (DIN)
unnamed: LED17.1 (DOUT), LED18.3 (DIN)
unnamed: LED18.1 (DOUT), LED19.3 (DIN)
unnamed: LED19.1 (DOUT), LED20.3 (DIN)
unnamed: LED20.1 (DOUT), LED21.3 (DIN)
unnamed: LED21.1 (DOUT), LED22.3 (DIN)
unnamed: LED22.1 (DOUT), LED23.3 (DIN)
unnamed: LED23.1 (DOUT), LED24.3 (DIN)
unnamed: LED24.1 (DOUT), LED25.3 (DIN)
unnamed: LED25.1 (DOUT), LED26.3 (DIN)
unnamed: LED26.1 (DOUT), LED27.3 (DIN)
unnamed: LED27.1 (DOUT), LED28.3 (DIN)
unnamed: LED28.1 (DOUT), LED29.3 (DIN)
unnamed: LED29.1 (DOUT), LED30.3 (DIN)
unnamed: LED30.1 (DOUT), LED31.3 (DIN)
unnamed: LED31.1 (DOUT), LED32.3 (DIN)
unnamed: LED32.1 (DOUT), LED33.3 (DIN)
unnamed: LED33.1 (DOUT), LED34.3 (DIN)
unnamed: LED34.1 (DOUT), LED35.3 (DIN)
unnamed: LED35.1 (DOUT), LED36.3 (DIN)
unnamed: LED36.1 (DOUT), LED37.3 (DIN)
unnamed: LED37.1 (DOUT), LED38.3 (DIN)
unnamed: LED38.1 (DOUT), LED39.3 (DIN)
unnamed: LED39.1 (DOUT), LED40.3 (DIN)
unnamed: LED40.1 (DOUT), LED41.3 (DIN)
unnamed: LED41.1 (DOUT), LED42.3 (DIN)
unnamed: LED42.1 (DOUT), LED43.3 (DIN)
unnamed: LED43.1 (DOUT), LED44.3 (DIN)
unnamed: LED44.1 (DOUT), LED45.3 (DIN)
unnamed: LED45.1 (DOUT), LED46.3 (DIN)
unnamed: LED46.1 (DOUT), LED47.3 (DIN)
unnamed: LED47.1 (DOUT), LED48.3 (DIN)
unnamed: LED48.1 (DOUT), LED49.3 (DIN)
unnamed: LED49.1 (DOUT), LED50.3 (DIN)
unnamed: LED50.1 (DOUT), LED51.3 (DIN)
unnamed: LED51.1 (DOUT), LED52.3 (DIN)
unnamed: LED52.1 (DOUT), LED53.3 (DIN)
unnamed: LED53.1 (DOUT), LED54.3 (DIN)
unnamed: LED54.1 (DOUT), LED55.3 (DIN)
unnamed: LED55.1 (DOUT), LED56.3 (DIN)
unnamed: LED56.1 (DOUT), LED57.3 (DIN)
unnamed: LED57.1 (DOUT), LED58.3 (DIN)
unnamed: LED58.1 (DOUT), LED59.3 (DIN)
unnamed: LED59.1 (DOUT), LED60.3 (DIN)
unnamed: LED60.1 (DOUT), LED61.3 (DIN)
unnamed: LED61.1 (DOUT), LED62.3 (DIN)
unnamed: LED62.1 (DOUT), LED63.3 (DIN)
unnamed: LED63.1 (DOUT), LED64.3 (DIN)
unnamed: LED64.1 (DOUT), LED65.3 (DIN)
unnamed: LED65.1 (DOUT), LED66.3 (DIN)
unnamed: LED66.1 (DOUT), LED67.3 (DIN)
unnamed: LED67.1 (DOUT), LED68.3 (DIN)
unnamed: LED68.1 (DOUT), LED69.3 (DIN)
unnamed: LED69.1 (DOUT), LED70.3 (DIN)
unnamed: LED70.1 (DOUT), LED71.3 (DIN)
unnamed: LED71.1 (DOUT), LED72.3 (DIN)
unnamed: LED72.1 (DOUT), LED73.3 (DIN)
unnamed: LED73.1 (DOUT), LED74.3 (DIN)
unnamed: LED74.1 (DOUT), LED75.3 (DIN)
unnamed: LED75.1 (DOUT), LED76.3 (DIN)
unnamed: LED76.1 (DOUT), LED77.3 (DIN)
unnamed: LED77.1 (DOUT), LED78.3 (DIN)
unnamed: LED78.1 (DOUT), LED79.3 (DIN)
unnamed: LED79.1 (DOUT), LED80.3 (DIN)
unnamed: LED80.1 (DOUT), LED81.3 (DIN)
unnamed: LED81.1 (DOUT), LED82.3 (DIN)
unnamed: R6.2, SW84.2
unnamed: R14.1, SW85.2, U1.26 (RUN)
unnamed: R9.2, U1.46 (USB_DM)
unnamed: R8.2, U1.47 (USB_DP)
unnamed: C94.2, C95.2, U1.23 (DVDD), U1.45 (VREG_VOUT), U1.50 (DVDD)
QSPI_SCLK: U1.52 (QSPI_SCLK), U4.6 (CLK)
QSPI_SD0: U1.53 (QSPI_SD0), U4.5 (DI/IO_{0})
QSPI_SD1: U1.55 (QSPI_SD1), U4.2 (DO/IO_{1})
QSPI_SD2: U1.54 (QSPI_SD2), U4.3 (~WP/IO_{2})
QSPI_SD3: U1.51 (QSPI_SD3), U4.7 (~HOLD/~RESET/IO_{3})
QSPI_SS: R6.1, R7.1, U4.1 (~CS)
R2: SW15.1, SW16.1, SW17.1, SW18.1, SW19.1, SW20.1, SW21.1, SW22.1, SW23.1, SW24.1, SW25.1, SW26.1, SW27.1, SW28.1, SW29.1, U1.35 (GPIO23)
R3: SW30.1, SW31.1, SW32.1, SW33.1, SW34.1, SW35.1, SW36.1, SW37.1, SW38.1, SW39.1, SW40.1, SW41.1, SW42.1, SW43.1, SW44.1, U1.15 (GPIO12)
R4: SW45.1, SW46.1, SW47.1, SW48.1, SW49.1, SW50.1, SW51.1, SW52.1, SW53.1, SW54.1, SW55.1, SW56.1, SW57.1, SW58.1, U1.16 (GPIO13)
R5: SW59.1, SW60.1, SW61.1, SW62.1, SW63.1, SW64.1, SW65.1, SW66.1, SW67.1, SW68.1, SW69.1, SW70.1, SW71.1, SW72.1, U1.17 (GPIO14)
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

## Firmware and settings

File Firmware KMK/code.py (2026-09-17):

import board
import random
import neopixel

from kmk.kmk_keyboard import KMKKeyboard
from kmk.keys import KC
from kmk.scanners import DiodeOrientation

keyboard = KMKKeyboard()


# Rows
keyboard.row_pins = (
    board.GP5,     # R1
    board.GP7,     # R2
    board.GP18,    # R3
    board.GP17,    # R4
    board.GP16,    # R5
    board.GP15,    # R6
)

# Columns
keyboard.col_pins = (
    board.GP19,    # C1
    board.GP20,    # C2
    board.GP21,    # C3
    board.GP22,    # C4
    board.GP23,    # C5
    board.GP24,    # C6
    board.GP25,    # C7
    board.GP4,     # C8 
    board.GP26,    # C9
    board.GP27,    # C10
    board.GP28,    # C11
    board.GP29,    # C12
    board.GP3,     # C13
    board.GP6,     # C14
)

keyboard.diode_orientation = DiodeOrientation.COL2ROW


LED_COUNT = 82
RGB_DATA_PIN = board.GP0
RGB_BRIGHTNESS = 0.18

pixels = neopixel.NeoPixel(
    RGB_DATA_PIN,
    LED_COUNT,
    brightness=RGB_BRIGHTNESS,
    auto_write=False,
    pixel_order=neopixel.GRB,
)
pixels.fill((0, 0, 0))
pixels.show()


def random_colour():
    # Avoid extremely dark colours so the pressed key is clearly visible.
    return (
        random.randint(45, 255),
        random.randint(45, 255),
        random.randint(45, 255),
    )


class PerKeyRGB:
    """Give the LED corresponding to a pressed matrix position a random colour."""

    def during_bootup(self, keyboard):
        pass

    def before_matrix_scan(self, keyboard):
        pass

    def after_matrix_scan(self, keyboard):
        pass

    def process_key(self, keyboard, key, is_pressed, int_coord):
        if is_pressed:
            # KMK matrix coordinates are row-major flattened coordinates.
            # This assumes LED1 follows the first key, LED2 the second, etc.
            led_index = int_coord
            if 0 <= led_index < LED_COUNT:
                pixels[led_index] = random_colour()
                pixels.show()
        return key

    def on_powersave_enable(self, keyboard):
        pass

    def on_powersave_disable(self, keyboard):
        pass

    def on_step(self, keyboard):
        pass


keyboard.extensions.append(PerKeyRGB())


keyboard.keymap = [
    # R1
    [KC.ESC, KC.N1, KC.N2, KC.N3, KC.N4, KC.N5, KC.N6,
     KC.N7, KC.N8, KC.N9, KC.N0, KC.MINS, KC.EQL, KC.BSPC],

    # R2
    [KC.TAB, KC.Q, KC.W, KC.E, KC.R, KC.T, KC.Y,
     KC.U, KC.I, KC.O, KC.P, KC.LBRC, KC.RBRC, KC.BSLS],

    # R3
    [KC.CAPS, KC.A, KC.S, KC.D, KC.F, KC.G, KC.H,
     KC.J, KC.K, KC.L, KC.SCLN, KC.QUOT, KC.ENT, KC.NO],

    # R4
    [KC.LSFT, KC.Z, KC.X, KC.C, KC.V, KC.B, KC.N,
     KC.M, KC.COMM, KC.DOT, KC.SLSH, KC.RSFT, KC.UP, KC.NO],

    # R5
    [KC.LCTL, KC.LGUI, KC.LALT, KC.SPC, KC.SPC, KC.SPC,
     KC.SPC, KC.SPC, KC.SPC, KC.RALT, KC.RGUI, KC.RCTL,
     KC.LEFT, KC.DOWN],

    # R6
    [KC.NO, KC.NO, KC.NO, KC.NO, KC.NO, KC.NO, KC.NO,
     KC.NO, KC.NO, KC.NO, KC.NO, KC.NO, KC.RIGHT, KC.NO],
]


if __name__ == "__main__":
    keyboard.go()
